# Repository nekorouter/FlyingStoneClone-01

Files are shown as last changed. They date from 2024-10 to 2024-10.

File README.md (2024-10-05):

# FlyingStoneClone-01
Gnuk-compatible GnuPG USB Token

## Reasons for starting this project

Because I lost my old GPG key's password and need a better way to carry GPG key with me.

Hardware key + paperkey seems like a better solution, and luckily I met with Niibe Yutaka, who made a open-source GPG USB key project called Gnuk Token. 

## Design Considerations

- STM32F103CBT6 is more hand-soldering friendly
- ST-Link v2 can be used as testing platform
- If the hardware looks more like a ST-Link than a some mystical USB stick, it may have some "camouflage" for that
- Maybe I can use those left board as a ST-Link...
- Possibility of adding a ACK button

## Difference from FlyingStone-01/FlyingStone-01-G/FlyingStone-01-ShenZhen

FST-01:
- STM32F103TB, 12MHz XTAL
- PA2,PA3 exposed

FST-01G:
- Using the same MCU/XTAL as FST-01

FST-01SZ:
- GD32F103TB, 12MHz XTAL
- PA3 exposed by using a hall effect sensor (DRV5032FA)

FSC-01:
- STM32F103CB, 8MHz XTAL
- PA5,PB0,PB13,PB14,PA2,PA3 exposed, in which PA5 is designed to be used as ACK button

## What need to be done next

- test if Gnuk is function correctly
- test if NeuG is working
- test ESD safety
- test if this board can be used as ST-Link v2

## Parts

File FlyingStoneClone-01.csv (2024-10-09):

# | Reference | Qty | Value | Footprint | DNP
1 | C1, C2 | 2 | 10uF | Capacitor_SMD:C_0402_1005Metric_Pad0.74x0.62mm_HandSolder
2 | C3, C4, C5, C6, C7, C8, C9 | 7 | 100nF | Capacitor_SMD:C_0402_1005Metric_Pad0.74x0.62mm_HandSolder
3 | D1 | 1 | Schottky | Diode_SMD:D_SOD-523
4 | D2 | 1 | LED | LED_SMD:LED_0402_1005Metric_Pad0.77x0.64mm_HandSolder
5 | J1 | 1 | USB3_A | Connector_USB:USB3_A_Plug_Wuerth_692112030100_Horizontal
6 | J2 | 1 | ST-Link | Connector_PinHeader_2.54mm:PinHeader_1x05_P2.54mm_Vertical
7 | Q1 | 1 | S9013 | Package_TO_SOT_SMD:SOT-23
8 | R1 | 1 | 1K5 | Resistor_SMD:R_0402_1005Metric_Pad0.72x0.64mm_HandSolder
9 | R2 | 1 | 10K | Resistor_SMD:R_0402_1005Metric_Pad0.72x0.64mm_HandSolder
10 | R3 | 1 | 39K | Resistor_SMD:R_0402_1005Metric_Pad0.72x0.64mm_HandSolder
11 | R4 | 1 | 100 | Resistor_SMD:R_0402_1005Metric_Pad0.72x0.64mm_HandSolder
12 | R5, R6, R7, R8 | 4 | 4K7 | Resistor_SMD:R_0402_1005Metric_Pad0.72x0.64mm_HandSolder
13 | R9, R10, R11 | 3 | 100K | Resistor_SMD:R_0402_1005Metric_Pad0.72x0.64mm_HandSolder
14 | R12 | 1 | 220 | Resistor_SMD:R_0402_1005Metric_Pad0.72x0.64mm_HandSolder
15 | SW1 | 1 | SW_Push | TestPoint:TestPoint_2Pads_Pitch2.54mm_Drill0.8mm
16 | TP1 | 1 | 3V3 | TestPoint:TestPoint_Pad_D1.0mm
17 | TP2 | 1 | DIO | TestPoint:TestPoint_Pad_D1.0mm
18 | TP3 | 1 | CLK | TestPoint:TestPoint_Pad_D1.0mm
19 | TP4 | 1 | GND | TestPoint:TestPoint_Pad_D1.0mm
20 | U1 | 1 | STM32F103CBTx | Package_QFP:LQFP-48_7x7mm_P0.5mm
21 | U2 | 1 | USBLC6-2SC6 | Package_TO_SOT_SMD:SOT-23-6
22 | U3 | 1 | LP2985-3.3 | Package_TO_SOT_SMD:SOT-23-5
23 | Y1 | 1 | 8MHz | Crystal:Crystal_SMD_3225-4Pin_3.2x2.5mm_HandSoldering

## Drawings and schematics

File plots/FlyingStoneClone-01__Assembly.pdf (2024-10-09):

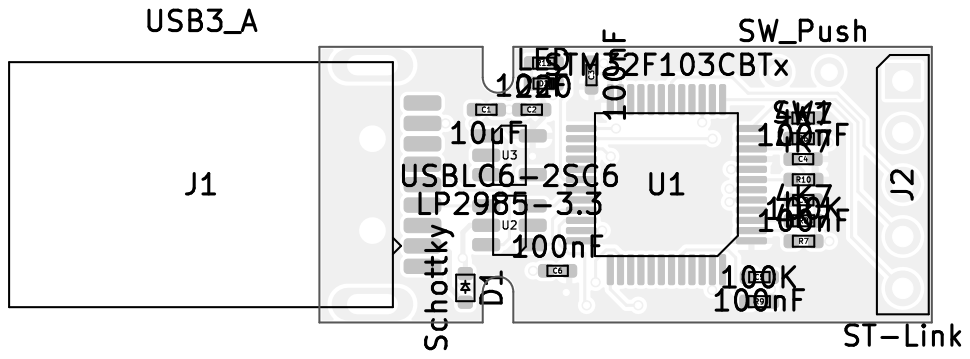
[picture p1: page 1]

Id: 1/1 Title: File: FlyingStoneClone-01.kicad_pcb Sheet:

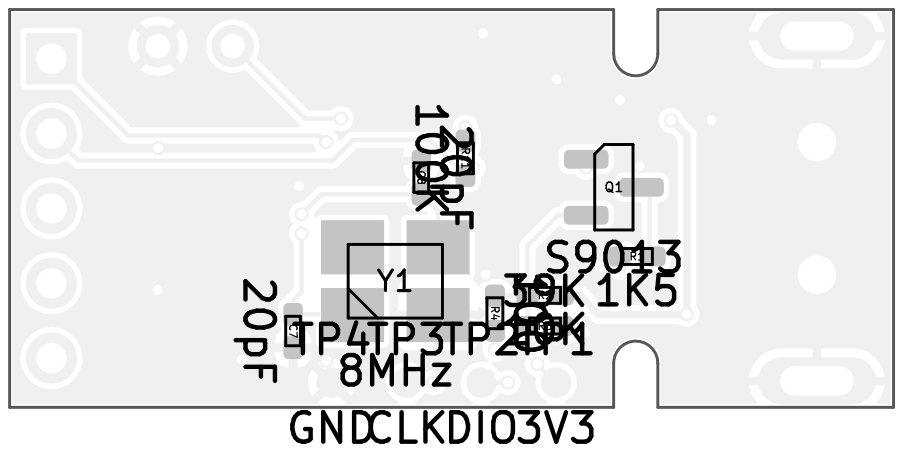
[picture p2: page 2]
D Date: KiCad; kicad; 7.0.9 Size: A4; Rev:

Id: 1/1 Title: File: FlyingStoneClone-01.kicad_pcb Sheet:

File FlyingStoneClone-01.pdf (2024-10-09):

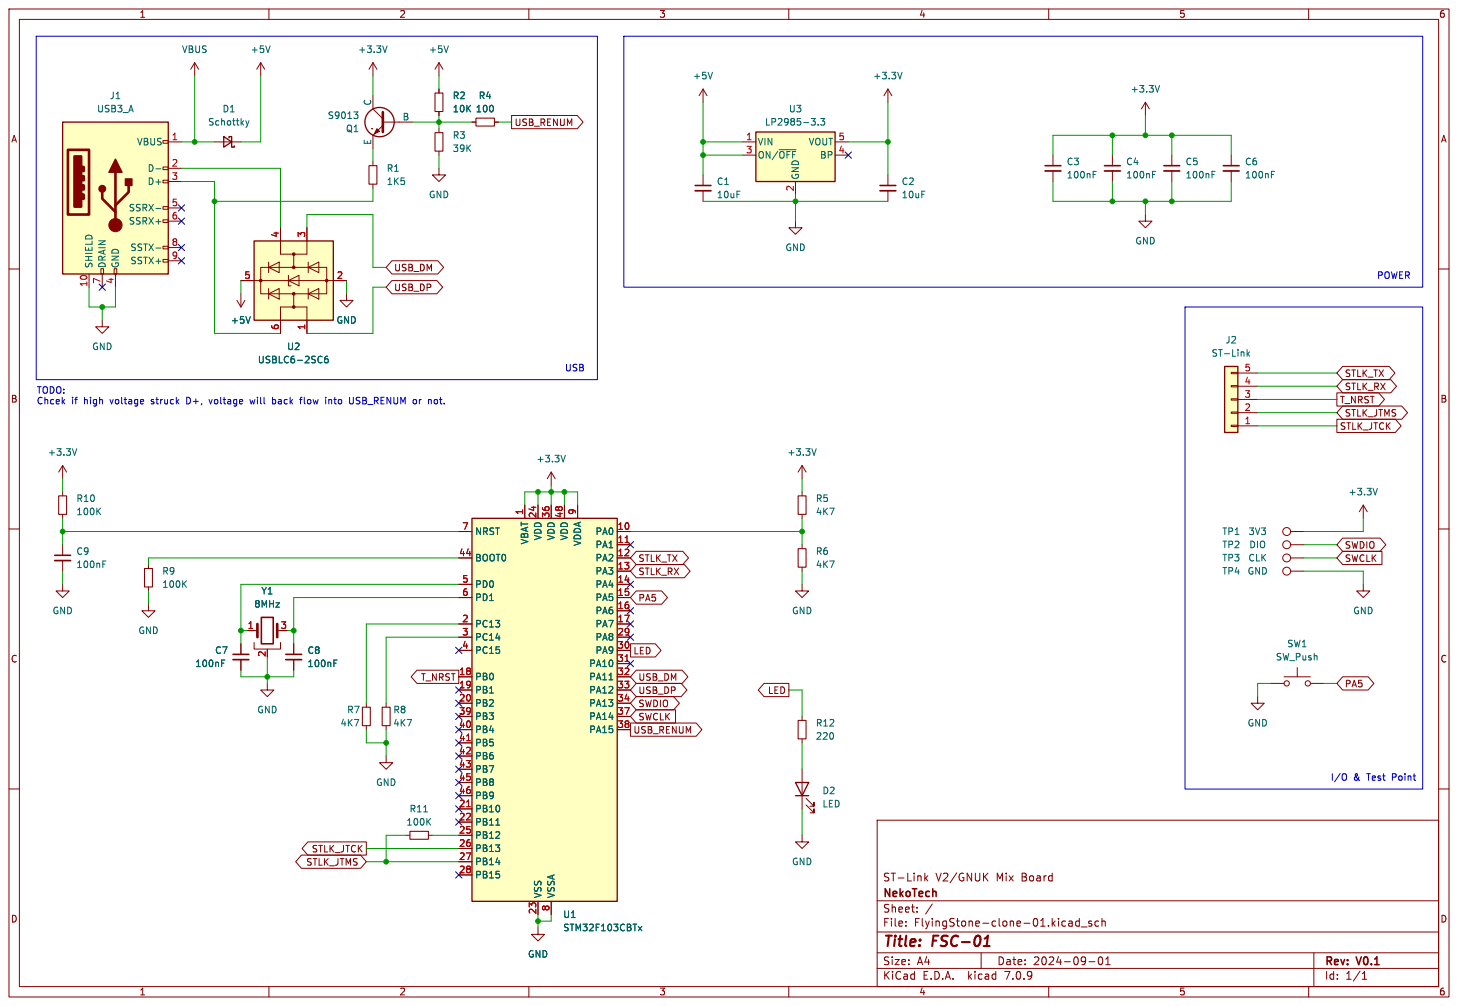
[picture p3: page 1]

2 ON/~{OFF} 3 BP 4 VOUT 5 U3

1 PA0 10 PA1 11 PA2 12 PA3 13 PA4 14 PA5 15 PA6 16 PA7 17 PB0 18 PB1 19 PC13 2 PB2 20 PB10 21 PB11 22 VSS 23 VDD 24 PB12 25 PB13 26 PB14 27 PB15 28 PA8 29 PC14 3 PA9 30 PA10 31 PA11 32 PA12 33 PA13 34 VDD 36 PA14 37 PA15 38 PB3 39 PC15 4 PB4 40 PB5 41 PB6 42 PB7 43 BOOT0 44 PB8 45 PB9 46 VDD 48 PD0 5 PD1 6 NRST 7 VSSA

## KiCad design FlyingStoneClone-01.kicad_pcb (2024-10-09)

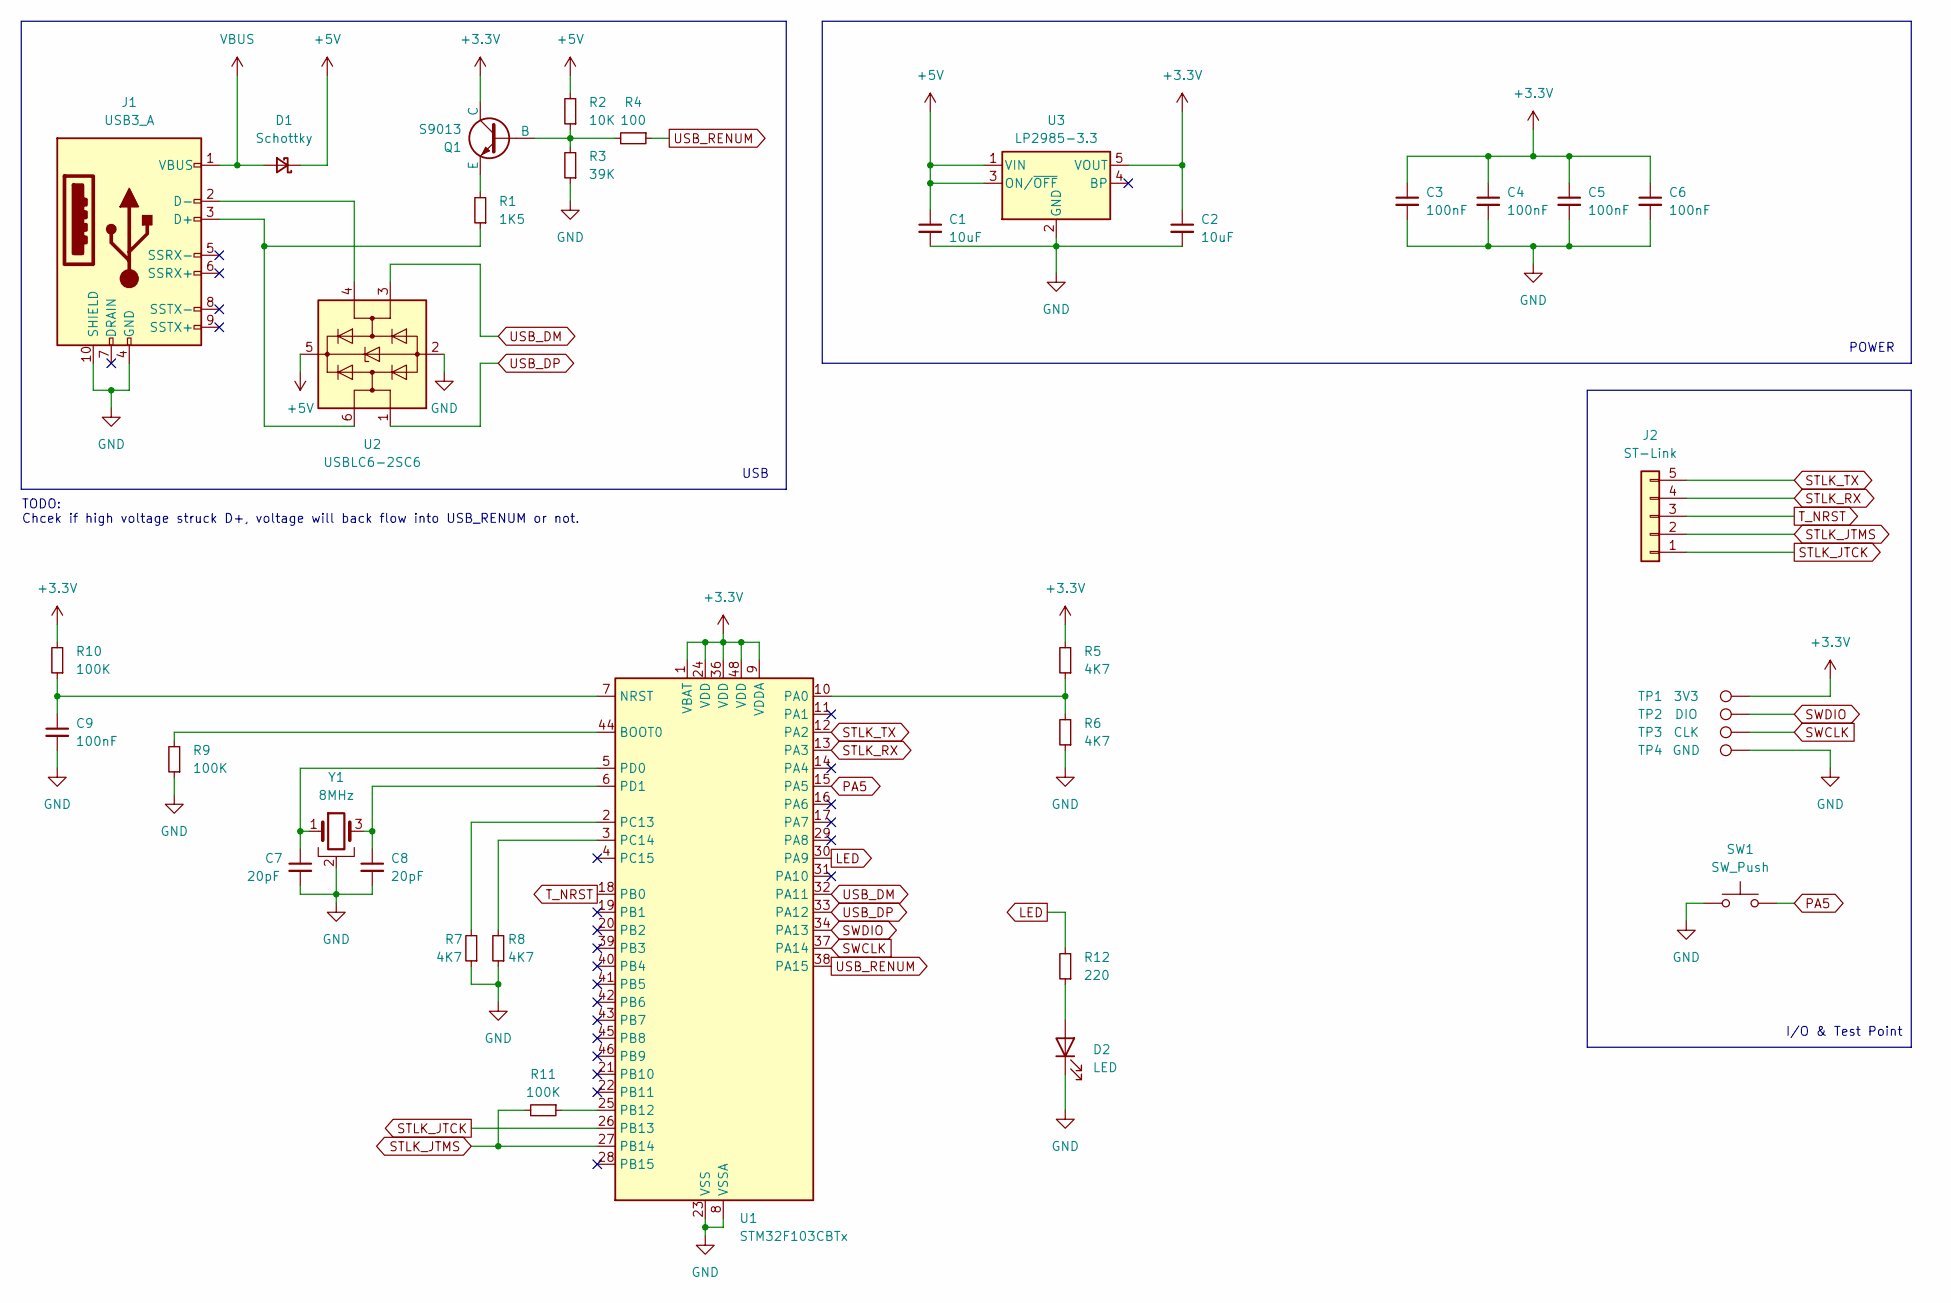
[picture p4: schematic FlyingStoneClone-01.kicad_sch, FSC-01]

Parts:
C1, C2: 10uF; C_0402_1005Metric_Pad0.74x0.62mm_HandSolder
C3, C4, C5, C6, C9: 100nF; C_0402_1005Metric_Pad0.74x0.62mm_HandSolder
C7, C8: 20pF; C_0402_1005Metric_Pad0.74x0.62mm_HandSolder
D1: Schottky; D_SOD-523
D2: LED; LED_0402_1005Metric_Pad0.77x0.64mm_HandSolder
J1: USB3_A; USB3_A_Plug_Wuerth_692112030100_Horizontal
J2: ST-Link; PinHeader_1x05_P2.54mm_Vertical
Q1: S9013; SOT-23
R1: 1K5; R_0402_1005Metric_Pad0.72x0.64mm_HandSolder
R2: 10K; R_0402_1005Metric_Pad0.72x0.64mm_HandSolder
R3: 39K; R_0402_1005Metric_Pad0.72x0.64mm_HandSolder
R4: 100; R_0402_1005Metric_Pad0.72x0.64mm_HandSolder
R5, R6, R7, R8: 4K7; R_0402_1005Metric_Pad0.72x0.64mm_HandSolder
R9, R10, R11: 100K; R_0402_1005Metric_Pad0.72x0.64mm_HandSolder
R12: 220; R_0402_1005Metric_Pad0.72x0.64mm_HandSolder
SW1: SW_Push; TestPoint_2Pads_Pitch2.54mm_Drill0.8mm
TP1: 3V3; TestPoint_Pad_D1.0mm
TP2: DIO; TestPoint_Pad_D1.0mm
TP3: CLK; TestPoint_Pad_D1.0mm
TP4: GND; TestPoint_Pad_D1.0mm
U1: STM32F103CBTx; LQFP-48_7x7mm_P0.5mm
U2: USBLC6-2SC6; SOT-23-6
U3: LP2985-3.3; SOT-23-5
Y1: 8MHz; Crystal_SMD_3225-4Pin_3.2x2.5mm_HandSoldering

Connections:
+3.3V: C2.1, C3.1, C4.1, C5.1, C6.1, Q1.1 (C), R5.2, R10.2, TP1.1, U1.1 (VBAT), U1.9 (VDDA), U1.24 (VDD), U1.36 (VDD), U1.48 (VDD), U3.5 (VOUT)
+5V: C1.1, D1.1 (K), R2.2, U2.5 (VBUS), U3.1 (VIN), U3.3 (ON/~OFF)
GND: C1.2, C2.2, C3.2, C4.2, C5.2, C6.2, C7.2, C8.2, C9.2, D2.1 (K), J1.4 (GND), J1.10 (SHIELD), R3.1, R6.1, R7.1, R8.1, R9.1, SW1.1, TP4.1, U1.8 (VSSA), U1.23 (VSS), U1.35 (VSS), U1.47 (VSS), U2.2 (GND), U3.2 (GND), Y1.2
LED: R12.2, U1.30 (PA9)
unnamed: D2.2 (A), R12.1
unnamed: J1.3 (D+), R1.1, U2.6 (I/O1)
unnamed: J1.2 (D-), U2.4 (I/O2)
unnamed: Q1.2 (B), R2.1, R3.2, R4.2
unnamed: Q1.3 (E), R1.2
unnamed: R9.2, U1.44 (BOOT0)
unnamed: C9.1, R10.1, U1.7 (NRST)
unnamed: R5.1, R6.2, U1.10 (PA0)
unnamed: R11.1, U1.25 (PB12)
unnamed: R7.2, U1.2 (PC13)
unnamed: R8.2, U1.3 (PC14)
unnamed: C7.1, U1.5 (PD0), Y1.1
unnamed: C8.1, U1.6 (PD1), Y1.3
PA5: SW1.2, U1.15 (PA5)
STLK_JTCK: J2.1, U1.26 (PB13)
STLK_JTMS: J2.2, R11.2, U1.27 (PB14)
STLK_RX: J2.4, U1.13 (PA3)
STLK_TX: J2.5, U1.12 (PA2)
SWCLK: TP3.1, U1.37 (PA14)
SWDIO: TP2.1, U1.34 (PA13)
T_NRST: J2.3, U1.18 (PB0)
USB_DM: U1.32 (PA11), U2.3 (I/O2)
USB_DP: U1.33 (PA12), U2.1 (I/O1)
USB_RENUM: R4.1, U1.38 (PA15)
VBUS: D1.2 (A), J1.1 (VBUS)

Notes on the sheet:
I/O & Test Point
TODO: Chcek if high voltage struck D+, voltage will back flow into USB_RENUM or not.
POWER
USB

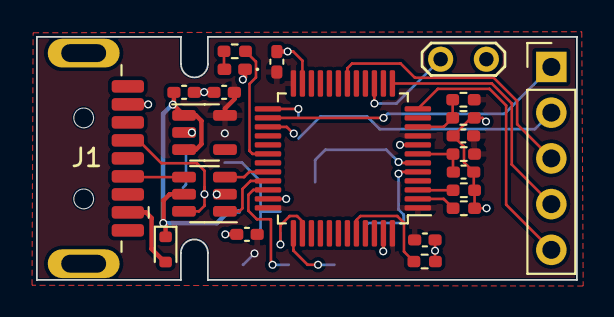
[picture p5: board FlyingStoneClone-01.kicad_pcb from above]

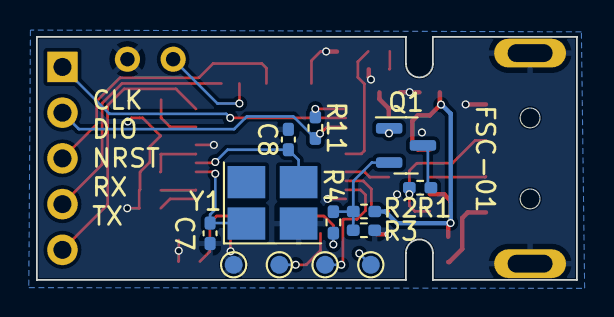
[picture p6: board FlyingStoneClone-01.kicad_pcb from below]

Board: 2 copper layers, 30.0 x 13.5 mm, 35 parts (13 on the bottom side), 29 nets.
